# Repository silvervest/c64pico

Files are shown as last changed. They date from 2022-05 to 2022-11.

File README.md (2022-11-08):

# C64 Pico

This is a tiny emulated C64 running on a Raspberry Pi Pico! Full details of the build can be found at https://www.youtube.com/watch?v=hgLhGpbC6E4

It was designed to dangle around my neck from a lanyard while I was wandering the halls and sections of PAX Aus 2022. It measures 102x81x16mm!

## Building

Wanna build one yourself? I go over the full build steps of this in the video linked above!

### BOM

I've put together an interactive BOM that you can reference - simply checkout the repo and open `ibom.html` in your browser.

Most of the parts can be figured out from the BOM or schematic, or are generic enough to just pick whatever fits (like all the caps and resistors), but some are pretty specific - here's a few purchasing links from the various sellers I used during this build;

* MicroSD card slot - https://www.aliexpress.com/item/32906952129.html
* TFT LCD - https://www.aliexpress.com/item/32837085500.html
* LCD FPC connector - https://www.digikey.com.au/en/products/detail/cvilux-usa/CF4240FH0R0-05-NH/15793119
* Crappy speaker - https://www.digikey.com.au/en/products/detail/cui-devices/CPT-9019S-SMT-TR/6012432
* Power switch - https://www.digikey.com.au/en/products/detail/c-k/JS102011SAQN/1640095
* Tac switches - https://www.digikey.com.au/en/products/detail/c-k/PTS-647-SN70-SMTR2-LFS/9649854
* LiPo battery - https://www.ebay.com.au/itm/143873020947

### PCBs

I designed the board to be fabricated specifically at JLCPCB with their SMT assembly service, so it should be pretty straightforward to get those made up.

Follow JLCPCB's guide on generating their bom and pos files from Kicad, and the components that can be placed by their SMT assembly service already have the correct and matching LCSC part number associated. Only the back layer needs assembly.

### Programming

The software provided for both the keyboard and MCUME modifications are not what I'd call "production-ready" either, and are really just a hack job. I might clean them up to be merged back one day, but probably not.

The keyboard code is in this repo underneath the keyboard directory, and can be programmed directly onto the ATmega328PB via ICSP headers using the Arduino software.

The RPi Pico code can be found in [my fork of the MCUME repo](https://github.com/silvervest/MCUME/tree/c64pico) under branch `c64pico` and you can follow the main instructions for building, installation and use.

### Face and back plates

The faceplate is just a plain PCB, and the PCB design files can be provided to your fab like any other. I recommend getting it HASL gold covered for extra shiny.

The backplate was designed to be laser cut from 1.5mm-2mm acrylic. I had mine created by [The Laser Cut Shop](https://thelasercutshop.com.au/) and the team there were excellent. I used the plotting function in KiCad to export DXF files for them to use.

## Instructions

Once it's complete, pop your SD card with .PRG files available into the slot and switch it on.

Pick whatever program you'd like to open and press the FIRE joystick button "pew pew". By default, the built-in joystick is "plugged" into JOY1 port, and you can switch that between JOY1/JOY2 using F1/F3 keys. Most C64 games use JOY2, so you might need to experiment.

At the BASIC prompt, type `LOAD` and press RETURN. That will load the .PRG file contents into RAM. Once READY, type `RUN` and press RETURN.

Enjoy! It's a bit slow, and some games are buggy as hell. I love playing Nebulus and Choplifter :)

## Development Photos

An early design, showing the overengineered reimplementation of the RP2040 Pico circuit and power management. It worked, but I didn't like it, so threw most of it out. You can also see I added full diodes into the keyboard for the hell of it.

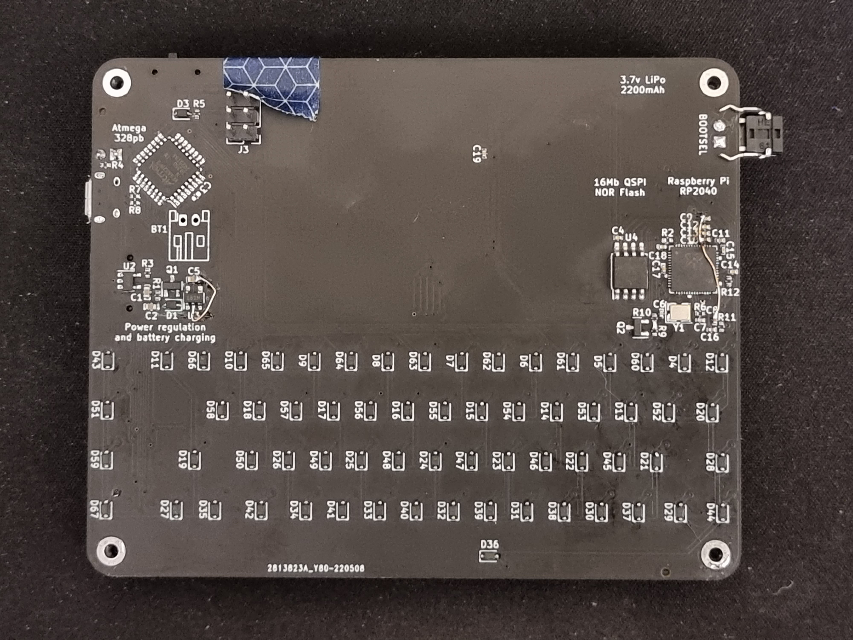
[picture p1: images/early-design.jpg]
Early Design


This was when I was writing the Arduino code for the keyboard and I2C protocol, and a test program running on the Pico decoding it and showing the output.

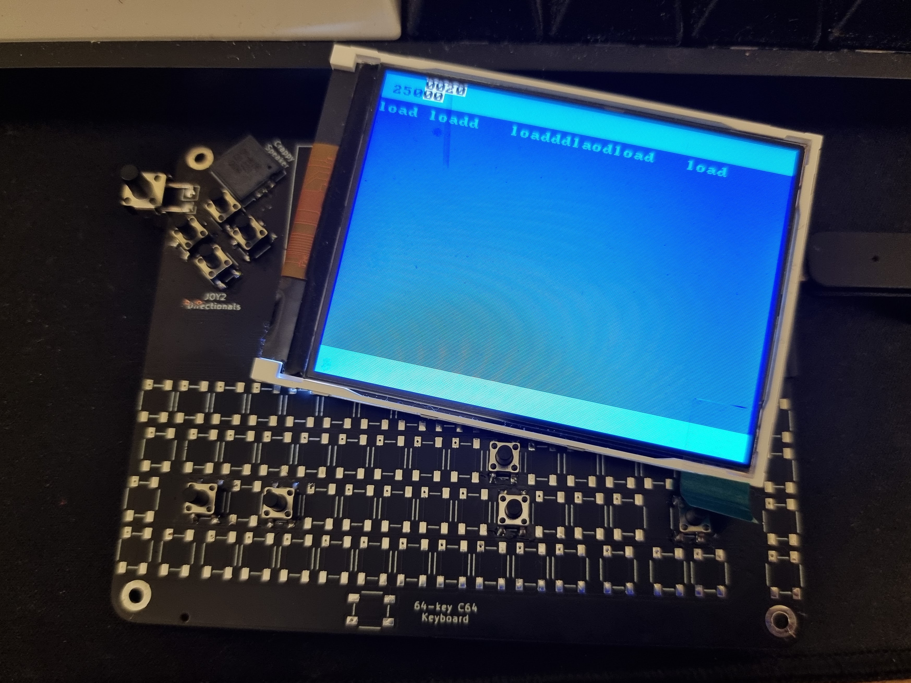
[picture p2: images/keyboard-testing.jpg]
Testing the keyboard


Finally fully working, so I booted up my favourite C64 game - Nebulus! The screen and battery were still held on with washi tape here.

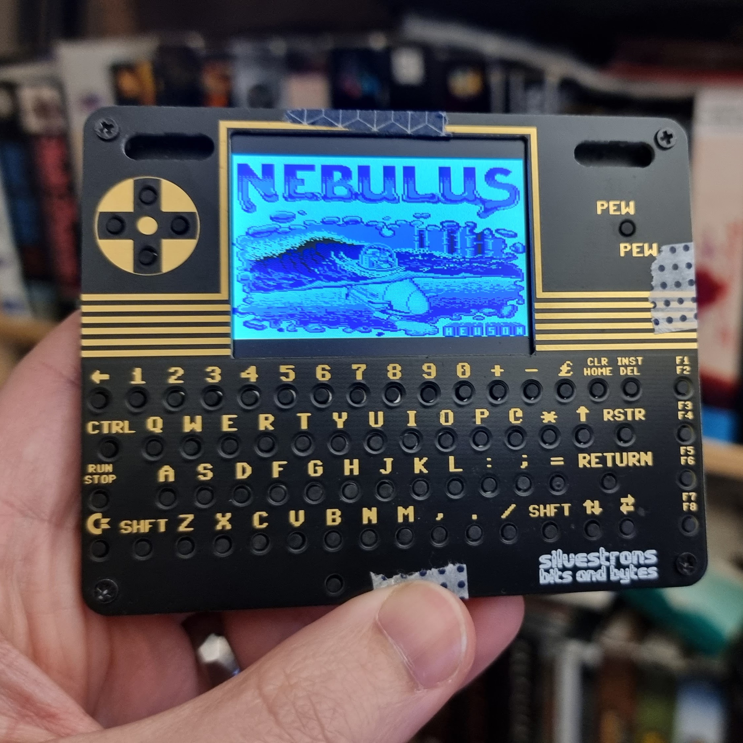
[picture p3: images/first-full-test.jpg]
Nebulus crack screen


Also Burnin' Rubber because that game is awesome and runs at almost full speed with no bugs that I could find!

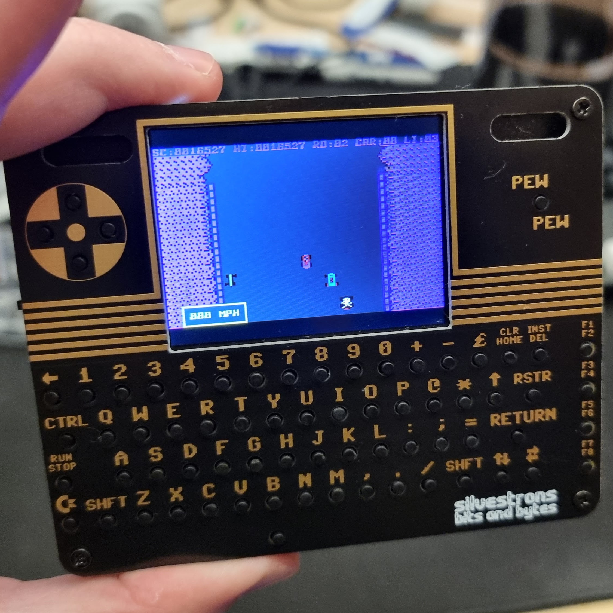
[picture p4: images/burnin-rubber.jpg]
Burnin' Rubber


And of course, I've gotta run the classic [10print maze](https://10print.org/)

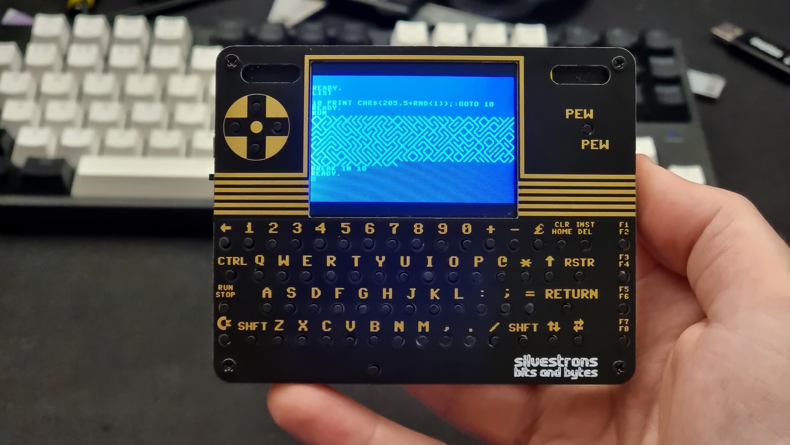
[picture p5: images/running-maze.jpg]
10print maze


## Acknowledgements

 - [MCUME](https://github.com/Jean-MarcHarvengt/MCUME)

    The base emulator at the guts of this, and was modified for my purposes.

 - [PICOmputer](https://github.com/bobricius/PICOmputer)

    Heavy inspiration taken from this project (and I stole the UDLR joystick layout)

## License

[CERN OHL v2 Strongly Reciprocal](https://choosealicense.com/licenses/cern-ohl-s-2.0/)

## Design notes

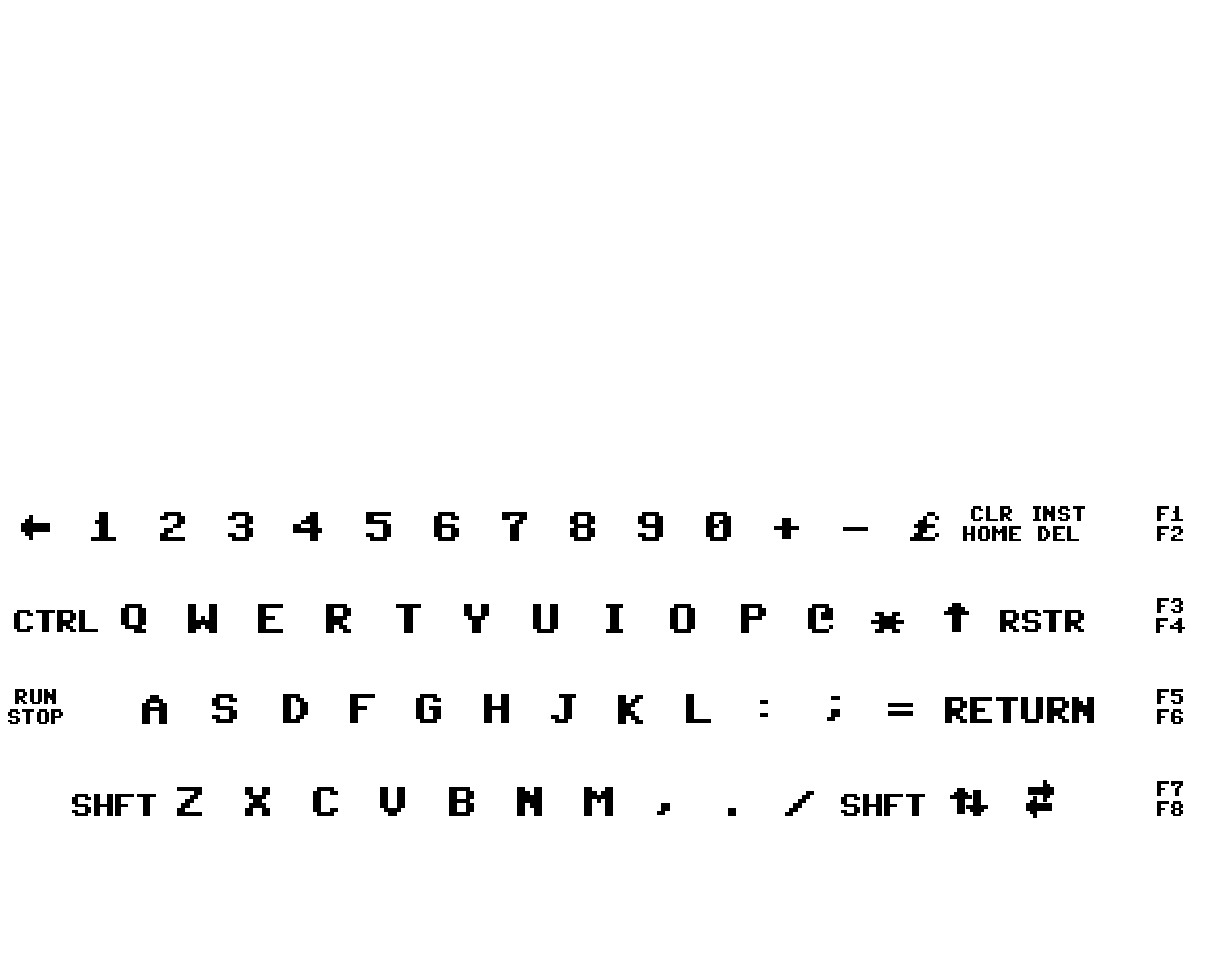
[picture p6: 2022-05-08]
faceplate-keys.png

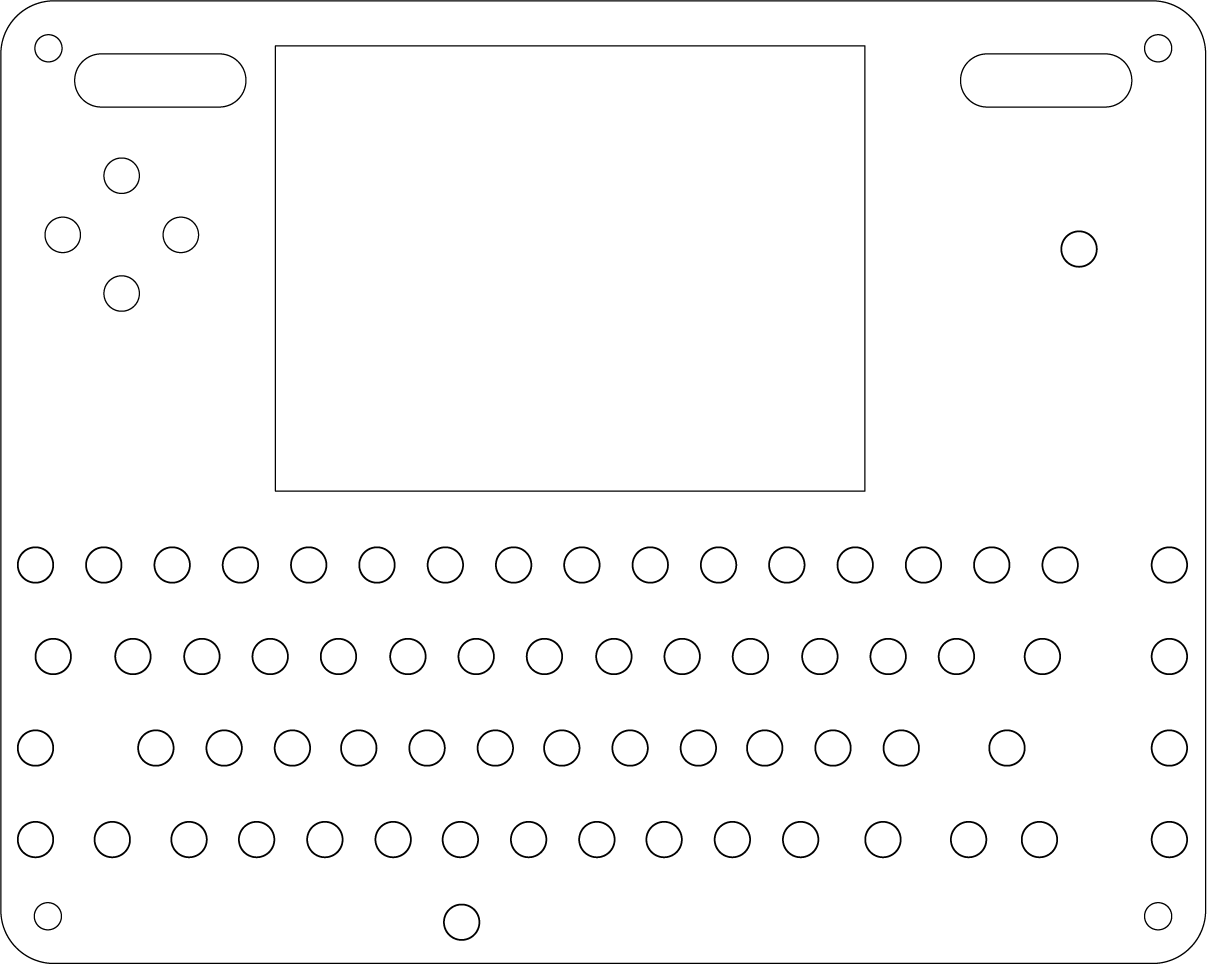
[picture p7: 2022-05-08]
holes.png

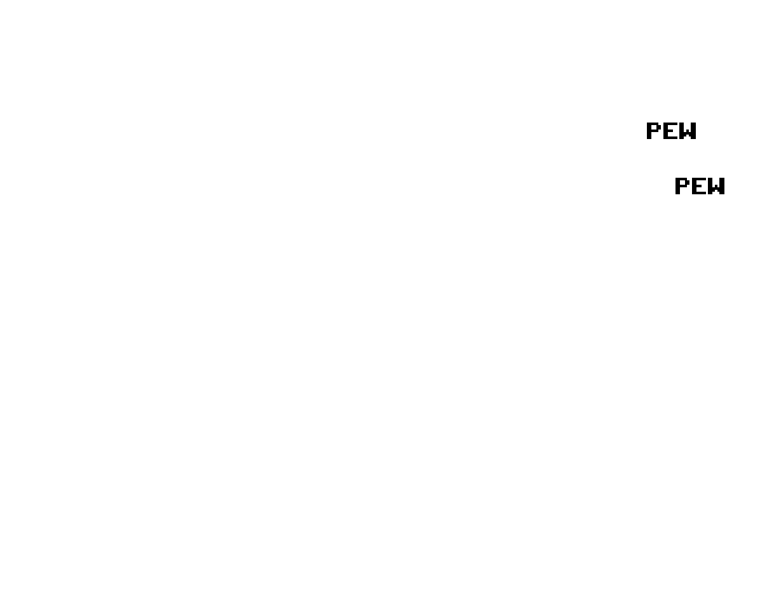
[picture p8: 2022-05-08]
pewpew.png

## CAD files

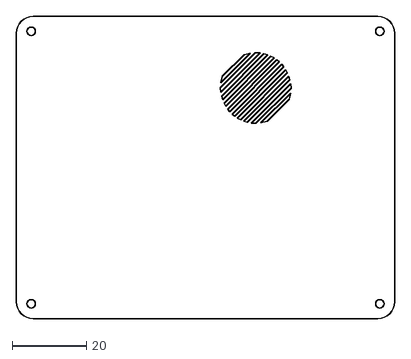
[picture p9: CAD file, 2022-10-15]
backplate/backplate-Edge_Cuts.dxf
102.0 x 81.5

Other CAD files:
backplate/backplate-B_Cu.dxf
backplate/backplate-F_Cu.dxf
backplate/backplate-B_Mask.dxf
backplate/backplate-B_Paste.dxf
backplate/backplate-B_Silkscreen.dxf
backplate/backplate-F_Mask.dxf
backplate/backplate-F_Paste.dxf
backplate/backplate-F_Silkscreen.dxf

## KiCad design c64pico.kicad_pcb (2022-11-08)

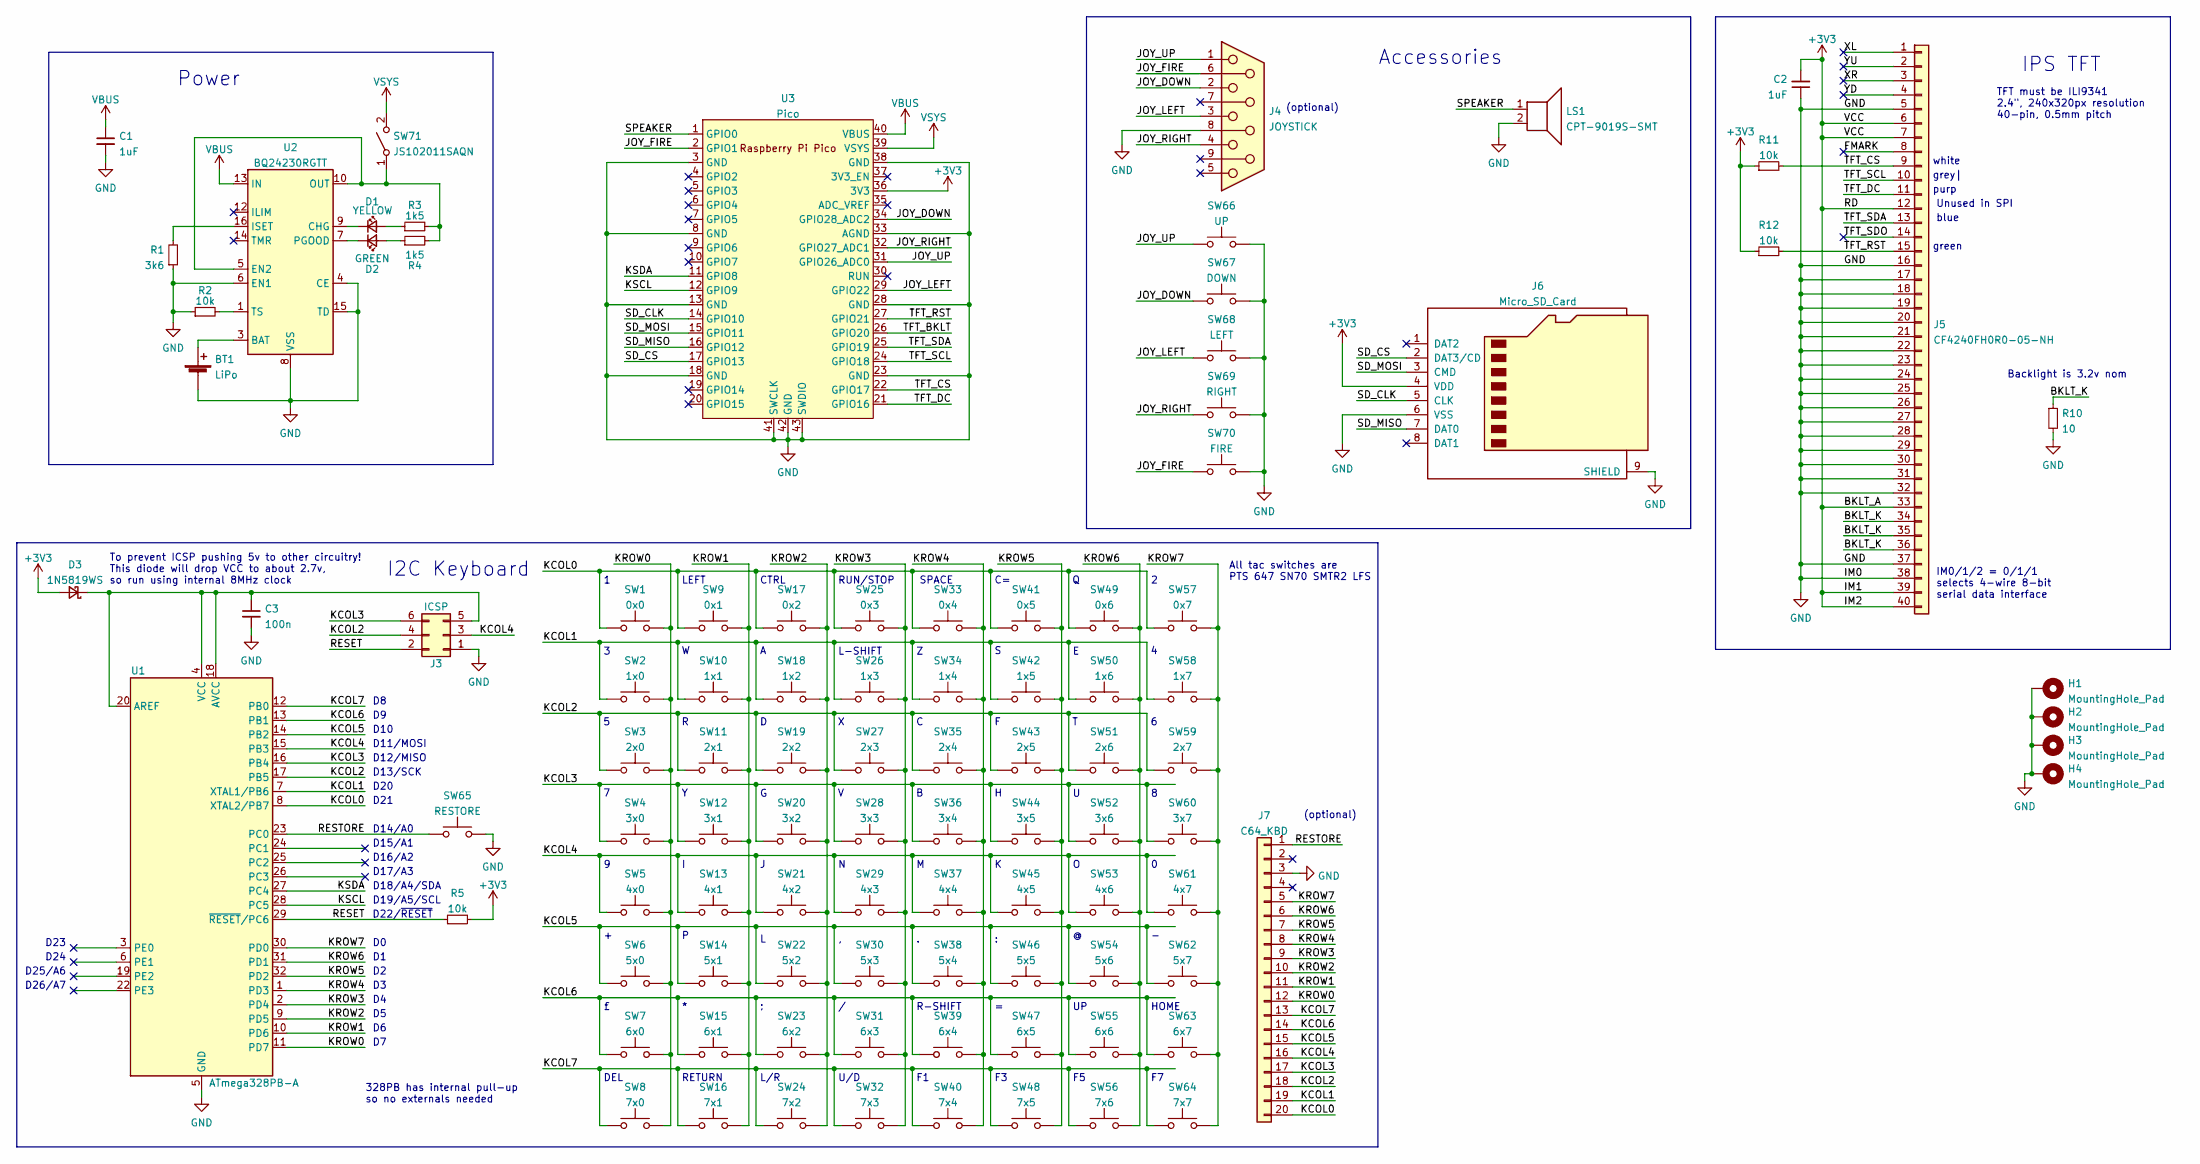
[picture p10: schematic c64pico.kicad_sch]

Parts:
BT1: LiPo; JST_PH_S2B-PH-K_1x02_P2.00mm_Horizontal
C1, C2: 1uF; C_0402_1005Metric; LCSC C52923
C3: 100n; C_0402_1005Metric; LCSC C1525
D1: YELLOW; LED_0603_1608Metric; LCSC C72038
D2: GREEN; LED_0603_1608Metric; LCSC C72043
D3: 1N5819WS; D_SOD-323
H1, H2, H3, H4: MountingHole_Pad; MountingHole_2.2mm_M2_Pad
J3: ICSP; PinHeader_2x03_P2.54mm_Vertical
J4: JOYSTICK
J5: CF4240FH0R0-05-NH; ILI9341
J6: Micro_SD_Card; Conn_uSDcard
J7: C64_KBD; PinHeader_1x20_P2.54mm_Vertical
LS1: CPT-9019S-SMT; Buzzer_CUI_CPT-9019S-SMT
R1: 3k6; R_0603_1608Metric; LCSC C22980
R2, R5, R11, R12: 10k; R_0402_1005Metric; LCSC C25744
R3, R4: 1k5; R_0402_1005Metric; LCSC C25867
R10: 10; R_0402_1005Metric
SW1: 0x0; SW_SPST_PTS647
SW2: 1x0; SW_SPST_PTS647
SW3: 2x0; SW_SPST_PTS647
SW4: 3x0; SW_SPST_PTS647
SW5: 4x0; SW_SPST_PTS647
SW6: 5x0; SW_SPST_PTS647
SW7: 6x0; SW_SPST_PTS647
SW8: 7x0; SW_SPST_PTS647
SW9: 0x1; SW_SPST_PTS647
SW10: 1x1; SW_SPST_PTS647
SW11: 2x1; SW_SPST_PTS647
SW12: 3x1; SW_SPST_PTS647
SW13: 4x1; SW_SPST_PTS647
SW14: 5x1; SW_SPST_PTS647
SW15: 6x1; SW_SPST_PTS647
SW16: 7x1; SW_SPST_PTS647
SW17: 0x2; SW_SPST_PTS647
SW18: 1x2; SW_SPST_PTS647
SW19: 2x2; SW_SPST_PTS647
SW20: 3x2; SW_SPST_PTS647
SW21: 4x2; SW_SPST_PTS647
SW22: 5x2; SW_SPST_PTS647
SW23: 6x2; SW_SPST_PTS647
SW24: 7x2; SW_SPST_PTS647
SW25: 0x3; SW_SPST_PTS647
SW26: 1x3; SW_SPST_PTS647
SW27: 2x3; SW_SPST_PTS647
SW28: 3x3; SW_SPST_PTS647
SW29: 4x3; SW_SPST_PTS647
SW30: 5x3; SW_SPST_PTS647
SW31: 6x3; SW_SPST_PTS647
SW32: 7x3; SW_SPST_PTS647
SW33: 0x4; SW_SPST_PTS647
SW34: 1x4; SW_SPST_PTS647
SW35: 2x4; SW_SPST_PTS647
SW36: 3x4; SW_SPST_PTS647
SW37: 4x4; SW_SPST_PTS647
SW38: 5x4; SW_SPST_PTS647
SW39: 6x4; SW_SPST_PTS647
SW40: 7x4; SW_SPST_PTS647
SW41: 0x5; SW_SPST_PTS647
SW42: 1x5; SW_SPST_PTS647
SW43: 2x5; SW_SPST_PTS647
SW44: 3x5; SW_SPST_PTS647
SW45: 4x5; SW_SPST_PTS647
SW46: 5x5; SW_SPST_PTS647
SW47: 6x5; SW_SPST_PTS647
SW48: 7x5; SW_SPST_PTS647
SW49: 0x6; SW_SPST_PTS647
SW50: 1x6; SW_SPST_PTS647
SW51: 2x6; SW_SPST_PTS647
SW52: 3x6; SW_SPST_PTS647
SW53: 4x6; SW_SPST_PTS647
SW54: 5x6; SW_SPST_PTS647
SW55: 6x6; SW_SPST_PTS647
SW56: 7x6; SW_SPST_PTS647
SW57: 0x7; SW_SPST_PTS647
SW58: 1x7; SW_SPST_PTS647
SW59: 2x7; SW_SPST_PTS647
SW60: 3x7; SW_SPST_PTS647
SW61: 4x7; SW_SPST_PTS647
SW62: 5x7; SW_SPST_PTS647
SW63: 6x7; SW_SPST_PTS647
SW64: 7x7; SW_SPST_PTS647
SW65: RESTORE; SW_SPST_PTS647
SW66: UP; SW_SPST_PTS647
SW67: DOWN; SW_SPST_PTS647
SW68: LEFT; SW_SPST_PTS647
SW69: RIGHT; SW_SPST_PTS647
SW70: FIRE; SW_SPST_PTS647
SW71: JS102011SAQN; SW_SPDT_CK-JS102011SAQN
U1: ATmega328PB-A; TQFP-32_7x7mm_P0.8mm
U2: BQ24230RGTT; VQFN-16-1EP_3x3mm_P0.5mm_EP1.68x1.68mm_ThermalVias; LCSC C138361
U3: Pico; RPi_Pico_SMD

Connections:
+3V3: C2.2, D3.2 (A), J5.6, J5.7, J5.12, J5.33, J5.39, J5.40, J6.4 (VDD), R5.2, R11.1, R12.1, U3.36 (3V3)
/BKLT_K: J5.34, J5.35, J5.36, R10.1
/FMARK: J5.8
/JOY_DOWN: J4.2, SW67.1, U3.34 (GPIO28_ADC2)
/JOY_FIRE: J4.6, SW70.1, U3.2 (GPIO1)
/JOY_LEFT: J4.3, SW68.1, U3.29 (GPIO22)
/JOY_RIGHT: J4.4, SW69.1, U3.32 (GPIO27_ADC1)
/JOY_UP: J4.1, SW66.1, U3.31 (GPIO26_ADC0)
/KCOL0: J7.20, SW1.1, SW9.1, SW17.1, SW25.1, SW33.1, SW41.1, SW49.1, SW57.1, U1.8 (XTAL2/PB7)
/KCOL1: J7.19, SW2.1, SW10.1, SW18.1, SW26.1, SW34.1, SW42.1, SW50.1, SW58.1, U1.7 (XTAL1/PB6)
/KCOL2: J3.4, J7.18, SW3.1, SW11.1, SW19.1, SW27.1, SW35.1, SW43.1, SW51.1, SW59.1, U1.17 (PB5)
/KCOL3: J3.6, J7.17, SW4.1, SW12.1, SW20.1, SW28.1, SW36.1, SW44.1, SW52.1, SW60.1, U1.16 (PB4)
/KCOL4: J3.3, J7.16, SW5.1, SW13.1, SW21.1, SW29.1, SW37.1, SW45.1, SW53.1, SW61.1, U1.15 (PB3)
/KCOL5: J7.15, SW6.1, SW14.1, SW22.1, SW30.1, SW38.1, SW46.1, SW54.1, SW62.1, U1.14 (PB2)
/KCOL6: J7.14, SW7.1, SW15.1, SW23.1, SW31.1, SW39.1, SW47.1, SW55.1, SW63.1, U1.13 (PB1)
/KCOL7: J7.13, SW8.1, SW16.1, SW24.1, SW32.1, SW40.1, SW48.1, SW56.1, SW64.1, U1.12 (PB0)
/KROW0: J7.12, SW1.2, SW2.2, SW3.2, SW4.2, SW5.2, SW6.2, SW7.2, SW8.2, U1.11 (PD7)
/KROW1: J7.11, SW9.2, SW10.2, SW11.2, SW12.2, SW13.2, SW14.2, SW15.2, SW16.2, U1.10 (PD6)
/KROW2: J7.10, SW17.2, SW18.2, SW19.2, SW20.2, SW21.2, SW22.2, SW23.2, SW24.2, U1.9 (PD5)
/KROW3: J7.9, SW25.2, SW26.2, SW27.2, SW28.2, SW29.2, SW30.2, SW31.2, SW32.2, U1.2 (PD4)
/KROW4: J7.8, SW33.2, SW34.2, SW35.2, SW36.2, SW37.2, SW38.2, SW39.2, SW40.2, U1.1 (PD3)
/KROW5: J7.7, SW41.2, SW42.2, SW43.2, SW44.2, SW45.2, SW46.2, SW47.2, SW48.2, U1.32 (PD2)
/KROW6: J7.6, SW49.2, SW50.2, SW51.2, SW52.2, SW53.2, SW54.2, SW55.2, SW56.2, U1.31 (PD1)
/KROW7: J7.5, SW57.2, SW58.2, SW59.2, SW60.2, SW61.2, SW62.2, SW63.2, SW64.2, U1.30 (PD0)
/KSCL: U1.28 (PC5), U3.12 (GPIO9)
/KSDA: U1.27 (PC4), U3.11 (GPIO8)
/RESET: J3.2, R5.1, U1.29 (~RESET/PC6)
/RESTORE: J7.1, SW65.1, U1.23 (PC0)
/SD_CLK: J6.5 (CLK), U3.14 (GPIO10)
/SD_CS: J6.2 (DAT3/CD), U3.17 (GPIO13)
/SD_MISO: J6.7 (DAT0), U3.16 (GPIO12)
/SD_MOSI: J6.3 (CMD), U3.15 (GPIO11)
/SPEAKER: LS1.1, U3.1 (GPIO0)
/TFT_BKLT: U3.26 (GPIO20)
/TFT_CS: J5.9, R11.2, U3.22 (GPIO17)
/TFT_DC: J5.11, U3.21 (GPIO16)
/TFT_RST: J5.15, R12.2, U3.27 (GPIO21)
/TFT_SCL: J5.10, U3.24 (GPIO18)
/TFT_SDA: J5.13, U3.25 (GPIO19)
/TFT_SDO: J5.14
/XL: J5.1
/XR: J5.3
/YD: J5.4
/YU: J5.2
GND: BT1.2 (-), C1.2, C2.1, C3.2, H1.1, H2.1, H3.1, H4.1, J3.1, J4.8, J5.5, J5.16, J5.17, J5.18, J5.19, J5.20, J5.21, J5.22, J5.23, J5.24, J5.25, J5.26, J5.27, J5.28, J5.29, J5.30, J5.31, J5.32, J5.37, J5.38, J6.6 (VSS), J6.9 (SHIELD), J7.3, LS1.2, R1.1, R2.1, R10.2, SW65.2, SW66.2, SW67.2, SW68.2, SW69.2, SW70.2, U1.5 (GND), U1.21 (GND), U2.4 (CE), U2.6 (EN1), U2.8 (VSS), U2.15 (TD), U2.17 (VSS), U3.3 (GND), U3.8 (GND), U3.13 (GND), U3.18 (GND), U3.23 (GND), U3.28 (GND), U3.33 (AGND), U3.38 (GND), U3.41 (SWCLK), U3.42 (GND), U3.43 (SWDIO)
unnamed: BT1.1 (+), U2.2 (BAT), U2.3 (BAT)
unnamed: C3.1, D3.1 (K), J3.5, U1.4 (VCC), U1.18 (AVCC), U1.20 (AREF)
unnamed: D1.1 (K), U2.9 (CHG)
unnamed: D1.2 (A), R3.1
unnamed: D2.1 (K), U2.7 (PGOOD)
unnamed: D2.2 (A), R4.1
unnamed: R1.2, U2.16 (ISET)
unnamed: R2.2, U2.1 (TS)
unnamed: R3.2, R4.2, SW71.1 (A), U2.5 (EN2), U2.10 (OUT), U2.11 (OUT)
VBUS: C1.1, U2.13 (IN), U3.40 (VBUS)
VSYS: SW71.2 (B), U3.39 (VSYS)

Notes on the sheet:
D22/~{RESET}
LEFT
All tac switches are PTS 647 SN70 SMTR2 LFS
D20
328PB has internal pull-up so no externals needed
TFT must be ILI9341 2.4", 240x320px resolution 40-pin, 0.5mm pitch
To prevent ICSP pushing 5v to other circuitry! This diode will drop VCC to about 2.7v, so run using internal 8MHz clock
RUN/STOP
RETURN
U/D
purp
D19/A5/SCL
R-SHIFT
Accessories
D21
Backlight is 3.2v nom
D11/MOSI
SPACE
CTRL
IM0/1/2 = 0/1/1 selects 4-wire 8-bit serial data interface
L/R
grey|
D25/A6
(optional)
D14/A0
white
HOME
I2C Keyboard
D23
Power
blue
D10
D13/SCK
D12/MISO
D18/A4/SDA
L-SHIFT
D26/A7
DEL
IPS TFT
D24

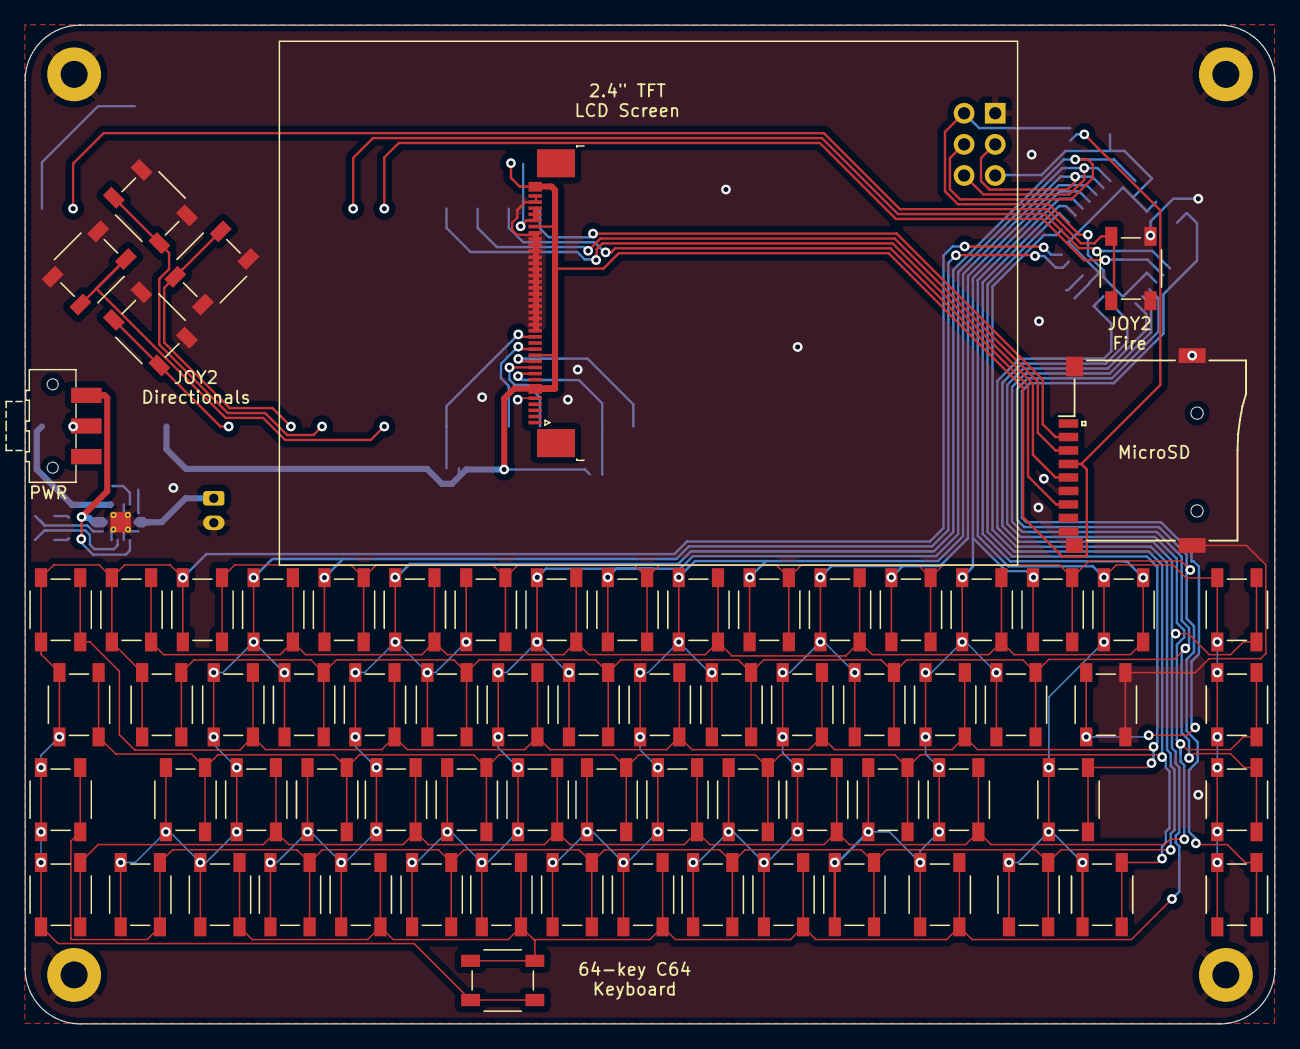
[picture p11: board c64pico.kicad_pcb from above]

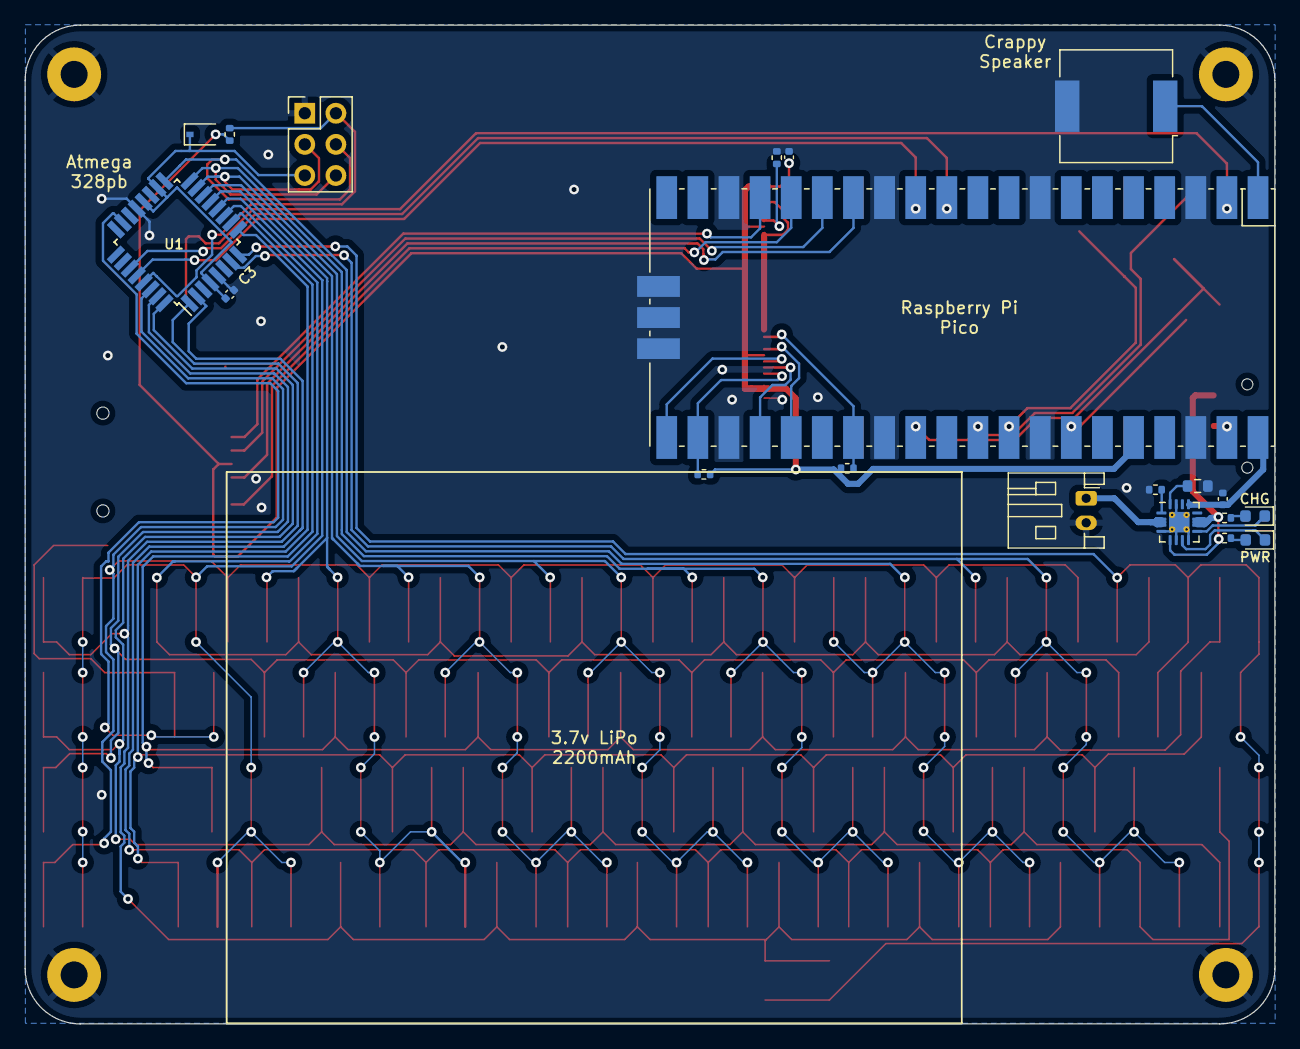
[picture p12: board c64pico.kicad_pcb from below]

Board: 2 copper layers, 102.0 x 81.5 mm, 97 parts (20 on the bottom side), 49 nets.

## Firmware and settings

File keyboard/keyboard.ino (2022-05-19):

#include <Wire.h>

// setup 9-byte array for response, 8 for the matrix, one lonesome byte just for the RESTORE key
// msg[9] = { [8-byte state of matrix], [1 byte state of RESTORE key] }
// the matrix state is comprised of eight bytes, each byte carries the value of one column of keys
// the column bytes are ordered high to low LSB, ie the top eight bits are for column 1 and the bottom eight bits are column 8
// the rows are ordered low to high LSB, so the row 1 is bit 1, row 8 is bit 8
// so if you're looking for row 6 in col 2 you would want to read the msg bit at position 8 + 8 + 5 (skip RESTORE byte, skip first column, skip row 5)
// or alternatively you could just look at (msg[1] & 0b00100000) :-)
static byte msg[9];

// iterate the keyboard matrix and extract which keys are currently pressed
void read_matrix(void) {
  byte *pos = &msg[0];
  uint8_t colBit;
  uint8_t rowBit;

  for (int col = 0; col < 8; col++) {
    colBit = (1 << col);
    // sink the column pin to ground
    DDRB |= colBit;
    PORTB &= ~colBit;
    
    for (int row = 0; row < 8; row++) {
      rowBit = (1 << row);
      
      // pull the row pin high via internal pull-up
      DDRD &= ~rowBit;
      PORTD |= rowBit;

      // data sheet says 1/2 - 1 1/2 cpu cycles for port sync
      // but this doesn't work in practice so send a bunch - doubled until it was stable
      asm("nop");
      asm("nop");
      asm("nop");
      asm("nop");
      asm("nop");
      asm("nop");
      asm("nop");
      asm("nop");
      asm("nop");
      asm("nop");
      asm("nop");
      asm("nop");
      asm("nop");
      asm("nop");
      asm("nop");
      asm("nop");
      asm("nop");
      asm("nop");
      asm("nop");
      asm("nop");
      asm("nop");
      asm("nop");
      asm("nop");
      asm("nop");
      asm("nop");
      asm("nop");
      asm("nop");
      asm("nop");
      asm("nop");
      asm("nop");
      asm("nop");
      asm("nop");
      asm("nop");
      asm("nop");
      asm("nop");
      asm("nop");
      asm("nop");
      asm("nop");
      asm("nop");
      asm("nop");
      
      // if we get our 5v pull up (HIGH), the button is not pressed
      // if we get ground (LOW), the button is pressed
      if (PIND & rowBit) {
        *pos &= ~rowBit;
      } else {
        *pos |= rowBit;
      }

      // disable the internal pull-up on this row
      DDRD &= ~rowBit;
      PORTD &= ~rowBit;
    }
    *pos++;

    // and now drive the column pin high also
    DDRB &= ~colBit;
    PORTB &= ~colBit;
  }

  // finally, get the restore pin and set the last byte
  *pos = PINC & (1<<PC0) ? 0x00 : 0xFF;
}

void i2c_respond(void) {
  Wire.write(msg, 9);
}

void setup() {
  // port config, yes I'm doing this via AVR constants, deal with it
  // PORTB (cols) will be input, and PORTD (rows) will be input with pull ups enabled
  DDRB  = 0b00000000;
  PORTB = 0b00000000;
  DDRD  = 0b00000000;
  PORTD = 0b11111111;

  // also port 0 on PORTC is input with pull up enabled
  DDRC |= (1<<DDC0);
  PORTC |= (1<<PC0);

  // setup i2c also - slave on address 8
  Wire.begin(8);
  Wire.setClock(400000);
  
  // respond to a request for data
  Wire.onRequest(i2c_respond);
}

// basically just read the matrix forever
void loop() {
  read_matrix();
  delay(2);
}

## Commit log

2022-05-08 updated top cover
    [cover-B_Cu.gbr, cover-B_Mask.gbr, cover-B_Paste.gbr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]
2022-05-09 nightly commit
    [paxbadge2022.kicad_pcb, paxbadge2022.kicad_sch]
2022-05-19 adding keyboard ino, syncing kicad after first prototype fixes
    [paxbadge2022.kicad_pcb, paxbadge2022.kicad_sch]
2022-10-15 clean up files for release
    [backplate-B_Cu.dxf, backplate-B_Mask.dxf, backplate-B_Paste.dxf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]
2022-10-15 adding license and readme, rename face/back plates
    [backplate-B_Cu.dxf, backplate-B_Mask.dxf, backplate-B_Paste.dxf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]
2022-11-08 add bom and update readme
    [c64pico.kicad_pcb, c64pico.kicad_sch]
